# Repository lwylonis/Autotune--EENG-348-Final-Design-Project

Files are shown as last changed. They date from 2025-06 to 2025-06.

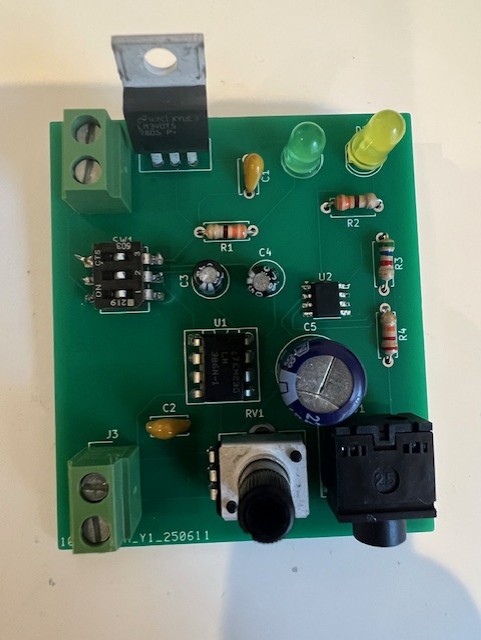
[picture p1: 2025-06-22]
Amplifier PCB Final.jpg

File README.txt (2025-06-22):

Pitch Modification/Autotune (Originally Developed May, 2025)

Authors: Leo Wylonis and Izzy Farrow

Overview
This Arduino sketch captures live audio at roughly 19 kHz, analyzes its fundamental pitch over short buffers, and immediately adjusts playback speed to bring the signal onto the nearest musical semitone. It combines a lightweight pitch-detection module with an 8-bit DAC so you can hear the output in real time.

User Interface
A three-color LED acts as your tuning meter: red when the input is flat, blue when it’s sharp, and green when the pitch is locked on target. A simple slide switch toggles between manual” mode—where a rotary encoder directly shifts playback speed—and automatic “autotune” mode—where the sketch captures a block of samples, computes the closest musical note, and then continually nudges playback speed until you’re in tune. Rotating the encoder gives you fine, real-time control over speed and tuning bias.

Setup & Wiring
Audio from a microphone preamp or line‐level source feeds the Arduino’s analog input. The digital I/O pins form an 8-bit DAC that drives your speaker or amplifier. The three LEDs share PWM pins and common power/ground rails. The encoder’s two signals and built-in button use pin-change interrupts, and a simple toggle switch on an analog pin flips between modes. All you need is common 5 V, ground, and the wiring diagram in the comments to get started.

How to Build
Copy sketch into a single folder, wire circuit according to schematic, and run with your choice of audio input!

What Happens Under the Hood
– Continuous Sampling: The ADC fires an interrupt at ~38 kHz, but only the top 8 bits are used to sample at ~19 kHz.
– Pitch Detection: A time-domain based difference function runs over 512 samples to find the signal’s period.
– Speed Adjustment: In manual mode, encoder turns adjust a speed multiplier. In autotune mode, the detected frequency is compared to a semitone scale, and the speed multiplier is incrementally changed until the LEDs indicate on-pitch.

EDIT: June 22- Added speaker amplifier schematic/pcb files for multipurpose variable gain audio amplifier with clipping detector circuit.

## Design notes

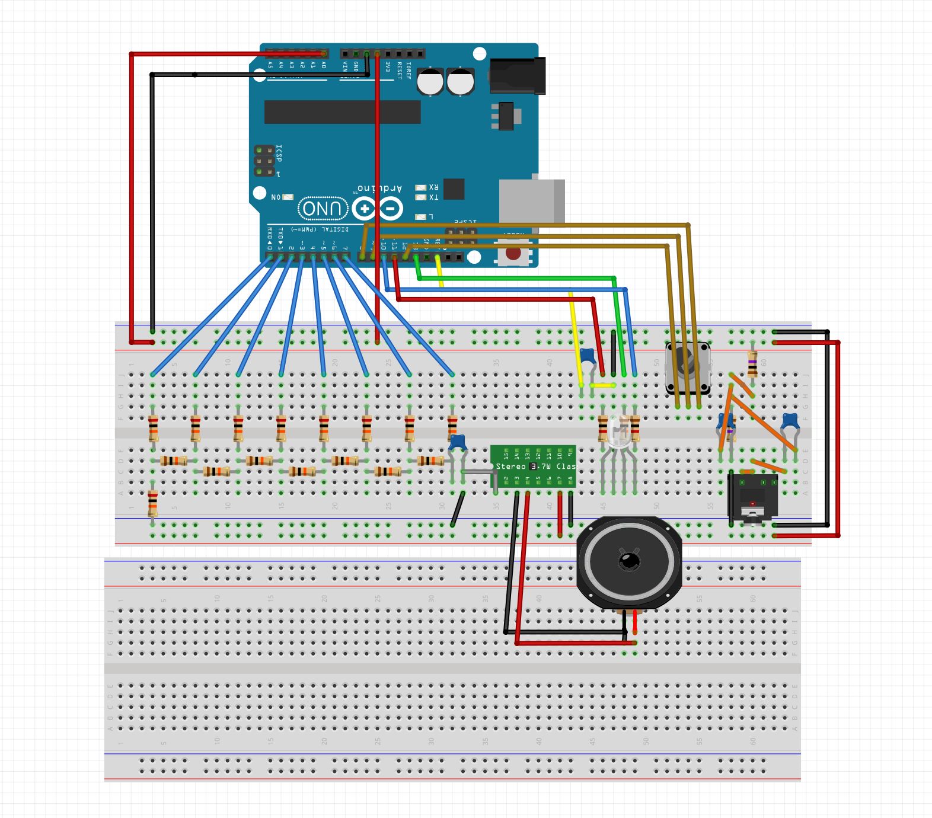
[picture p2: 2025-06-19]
Lab 5 Schematic.png

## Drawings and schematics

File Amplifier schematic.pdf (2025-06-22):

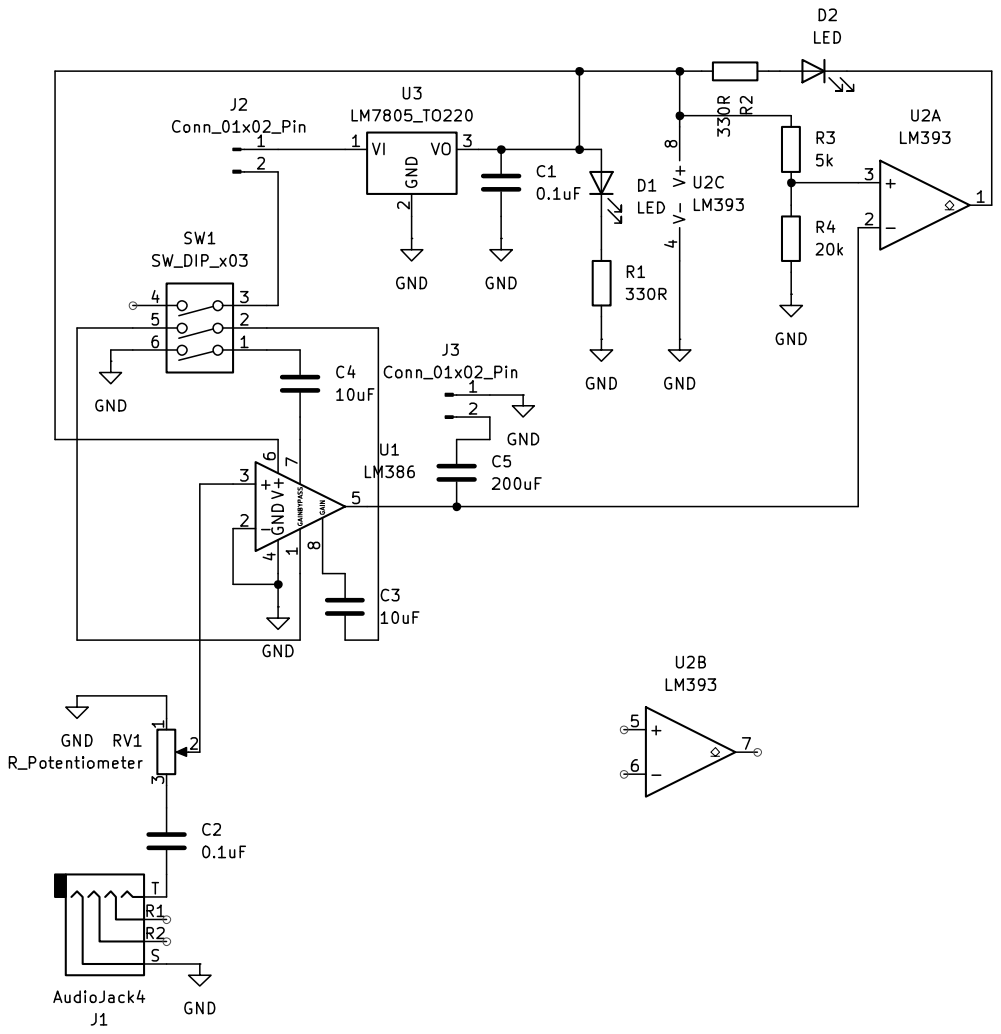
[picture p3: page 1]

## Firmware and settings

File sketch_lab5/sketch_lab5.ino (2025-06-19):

#include <Arduino.h>
#include <math.h>
#include <stdint.h>
#include "pitch_detection.h"

// Pin definitions
#define LED_RED_PIN 11
#define LED_GREEN_PIN 13
#define LED_BLUE_PIN 10
#define ENCODER_CLK 8
#define ENCODER_DT 9
#define ENCODER_BUTTON 12
#define AUDIO_PIN A5
#define MODE_SWITCH_PIN A0

// Buffer and playback constants
#define BUFFER_LENGTH 512
#define BUFFER_MASK (BUFFER_LENGTH - 1)
#define PHASE_SHIFT 7
#define SPEED_CENTER 128
#define SPEED_MIN 1
#define SPEED_MAX 255

// Snap frequency to nearest semitone and update LEDs
static float snapToNearestNote(float frequency) {
    float semiPosition = 12.0f * M_LOG2E * logf(frequency / 65.41f);
    int16_t semiIndex = (int16_t)roundf(semiPosition);
    float semiDiff = semiIndex - semiPosition;
    int redLevel = constrain((int)roundf(semiDiff * 512.0f), 0, 255);
    int blueLevel = constrain((int)roundf((0.5f - semiDiff) * 512.0f), 0, 255);
    analogWrite(LED_RED_PIN, redLevel);
    analogWrite(LED_BLUE_PIN, blueLevel);
    return 65.41f * powf(2.0f, semiIndex / 12.0f);
}

// ADC ISR: fill ring buffer, output tone, capture samples
ISR(ADC_vect) {
    static uint8_t  ringBuffer[BUFFER_LENGTH];
    static uint16_t writePos = 0;
    static uint16_t phasePosition = 0;
    static uint16_t capturePos = BUFFER_LENGTH;

    uint8_t sampleVal = ADCH;
    ringBuffer[writePos] = sampleVal;
    writePos = (writePos + 1) & BUFFER_MASK;
    phasePosition += playbackSpeed;
    PORTD = ringBuffer[phasePosition >> PHASE_SHIFT];
    if (captureFlag) {
        if (capturePos >= BUFFER_LENGTH) capturePos = 0;
        capBuffer[capturePos++] = sampleVal;
        if (capturePos >= BUFFER_LENGTH) {
            captureFlag = false;
            capturePos = BUFFER_LENGTH;
        }
    }
}

// Encoder ISR: adjust speed
ISR(PCINT0_vect) {
    if (digitalRead(ENCODER_BUTTON) == LOW) adjustment = 0;
    static bool lastClkState = true;
    bool clkState = digitalRead(ENCODER_CLK);
    if (clkState != lastClkState) {
        lastClkState = clkState;
        if (digitalRead(ENCODER_DT) == clkState) {
            if (adjustment > -128) adjustment--;
        } else {
            if (adjustment < 127) adjustment++;
        }
    }
}
static uint8_t capBuffer[BUFFER_LENGTH];
volatile uint8_t playbackSpeed = SPEED_CENTER;
volatile int8_t adjustment = 0;
volatile bool captureFlag = false;
void setup() {
    noInterrupts();
    // Configure I/O
    pinMode(AUDIO_PIN, INPUT);
    pinMode(MODE_SWITCH_PIN, INPUT_PULLUP);
    for (uint8_t pin = 0; pin < 8; ++pin) pinMode(pin, OUTPUT);
    pinMode(LED_RED_PIN, OUTPUT);
    pinMode(LED_GREEN_PIN, OUTPUT);
    pinMode(LED_BLUE_PIN, OUTPUT);
    pinMode(ENCODER_CLK, INPUT);
    pinMode(ENCODER_DT, INPUT);
    pinMode(ENCODER_BUTTON, INPUT_PULLUP);
    // Initialize detector
    pitch_init(0.05f);
    // ADC: AVcc ref, left adjust, channel A5
    ADMUX  = (1<<REFS0)|(1<<ADLAR)|AUDIO_PIN;
    ADCSRA = (1<<ADPS2)|(1<<ADPS1)|(1<<ADATE)|(1<<ADEN)|(1<<ADIE)|(1<<ADSC);
    ADCSRB = 0;
    // Enable pin-change interrupts for encoder
    PCMSK0 = bit(PCINT0)|bit(PCINT1)|bit(PCINT4);
    PCIFR  = bit(PCIF0);
    PCICR  = bit(PCIE0);
    interrupts();
}

void loop() {
    if (digitalRead(MODE_SWITCH_PIN) != HIGH) {
        digitalWrite(LED_GREEN_PIN, HIGH);
        playbackSpeed = constrain(SPEED_CENTER + adjustment, SPEED_MIN, SPEED_MAX);
        analogWrite(LED_RED_PIN,  SPEED_CENTER - 1 - adjustment);
        analogWrite(LED_BLUE_PIN, SPEED_CENTER + adjustment);
    } else {
        digitalWrite(LED_GREEN_PIN, LOW);
        captureFlag = true;
        while (captureFlag) {};
        float detected = roundf(pitch_detect(capBuffer));
        if (detected >= 78.0f) {
            static float smoothFreq = 0;
            smoothFreq = 0.5f * (smoothFreq + detected);
            float targetFreq = snapToNearestNote(smoothFreq);
            playbackSpeed = constrain((int)roundf(targetFreq * SPEED_CENTER / smoothFreq) + adjustment, SPEED_MIN, SPEED_MAX);
        } else {
            playbackSpeed = constrain(SPEED_CENTER + adjustment, SPEED_MIN, SPEED_MAX);
            analogWrite(LED_RED_PIN,  0);
            analogWrite(LED_BLUE_PIN, 0);
        }
    }
}

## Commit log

2025-06-22 Add files via upload
    Added KiCAD files, circuit schematic, and PCB image for variable gain audio amplifier with clipping detector.
    [Amplifier PCB.kicad_sch]
2025-06-22 Rename Schematic.pdf to Amplifier schematic.pdf
2025-06-22 Rename thumbnail_IMG_0188.jpg to Amplifier PCB Final.jpg
2025-06-22 Update README.txt
    Added variable speaker amplifier PCB info to README
